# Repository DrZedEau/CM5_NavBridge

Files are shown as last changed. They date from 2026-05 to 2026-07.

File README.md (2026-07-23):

# CM5 NavBridge

A Raspberry Pi Compute Module 5 carrier board designed for BMW E-Series vehicles equipped with the OEM navigation system (E46, E39, E85, and similar platforms).

The CM5 NavBridge installs inline between the factory wiring harness and the BMW MK3/MK4 navigation module, allowing a Raspberry Pi CM5 to integrate with the original infotainment system while preserving the OEM look and functionalities.

Its primary purpose is to provide modern features such as Apple CarPlay and Android Auto through the Raspberry Pi while continuing to use the factory display, controls, and audio system.

<p align="center">
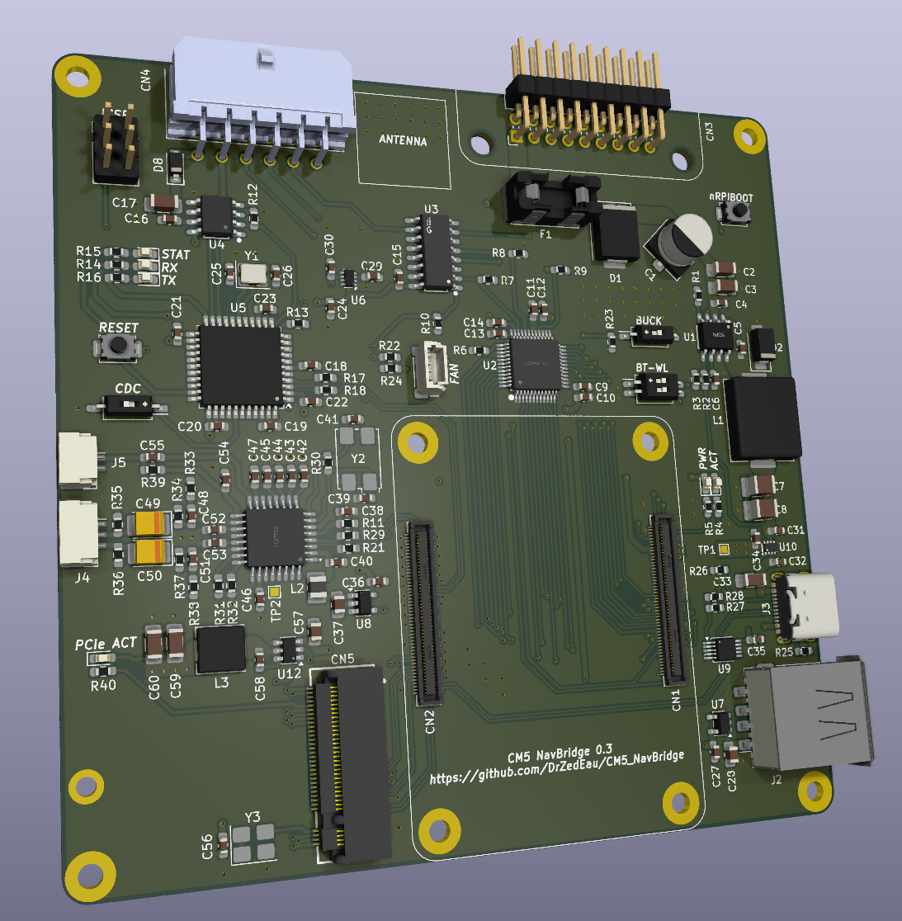
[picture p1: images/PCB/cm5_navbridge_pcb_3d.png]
  
</p>

---

## Overview

The board interfaces directly with the factory navigation module and provides:

- Video output from the Raspberry Pi to the OEM BMW display
- Stereo audio output for integration with the factory AUX input or CDC interface
- Microphone input supporting both OEM and aftermarket microphones
- Integration with the BMW I-Bus for power management and button control
- CDC emulation via the onboard microcontroller

The hardware is designed to work alongside the **LIVI** project, which provides the software environment for Apple CarPlay and Android Auto support.

Future software releases are planned to include a dedicated application, enabling the Raspberry Pi to function as a standalone infotainment platform with features such as:

- Music streaming
- Hands-free calling
- Navigation
- Media playback
- Additional connected vehicle features

---

## Features

### Hardware

- Automotive-grade 5V and 3.5A power supply using the **LMR14030-Q1**
- USB-C interface for Raspberry Pi flashing
- Automatic selection between USB-C and USB Type-A
- 24-bit video DAC (**ADV7125**) for OEM display output
- Integrated **PCM2912A** USB audio codec
  - Stereo line output
  - Mono microphone input
- M.2 PCIe M-Key (2230) expansion slot for additional modules such as GPS or DAB+

### Vehicle Integration

- Reads BMW I-Bus through an onboard **ATA663254** LIN transceiver
- **ATmega32U4** microcontroller for:
  - Raspberry Pi power management
  - OEM button translation
  - CD changer (CDC) emulation
- No modifications to the factory wiring or infotainment system are required

---

## Repository Structure

```text
hardware/      KiCad hardware design files
software/      Raspberry Pi software and MCU firmware
3D/            STL files for printed components
documentation/ Installation and project documentation
```

---

## Documentation

[0. Bill of materials](documentation/BOM.md)<br>

[1. Prepare the PCB](documentation/PCB.md)<br>

[2. Flash the NavBridge](documentation/FLASH.md)<br>

[3. Install the NavBridge](documentation/INSTALL.md)<br>

---

## Project Status

The hardware is currently functional and has been successfully tested on:

- BMW Z4 E86 with MK4 Navigation Module

Testing on additional E-Series platforms and navigation variants is ongoing.

---

## Roadmap

- Improve PCB layout for the next hardware revisions
- Expand compatibility testing across additional BMW platforms
- Develop a dedicated application

---

## Contributing

Contributions are welcome.

Bug reports, hardware improvements, firmware enhancements, and documentation updates are all appreciated. Please open an issue or submit a pull request if you would like to contribute.

---

## References

- LIVI project https://github.com/f-io/LIVI
- BMW Wiring Diagram System (WDS) https://bmwteka.com/wds/en/e85/e82460cf 
- BMW On-Board Monitor documentation https://bmwteka.com/wds/en/e85/1b7f9876
- Community resources https://www.e46fanatics.com/threads/bmw-on-board-monitor-without-navigation-unit.1303552

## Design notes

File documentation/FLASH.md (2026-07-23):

# Flash the RPI CM5

Locate the nRPIBOOT switch and press it down while connecting the USB-C cable to a PC:

<p align="center">
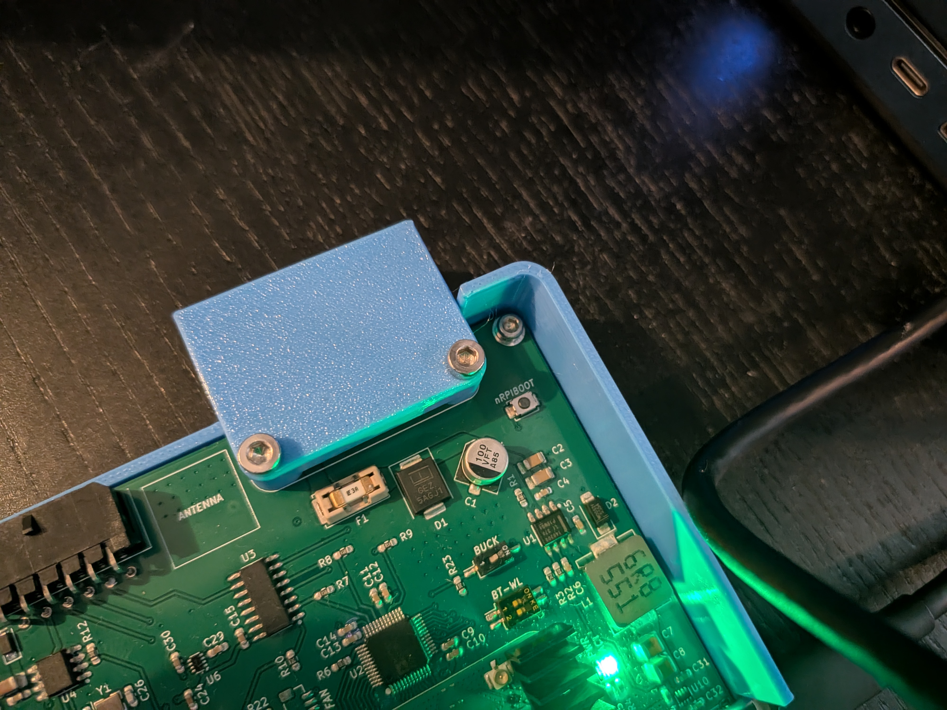
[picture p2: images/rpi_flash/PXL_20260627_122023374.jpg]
  
</p>

<p align="center">
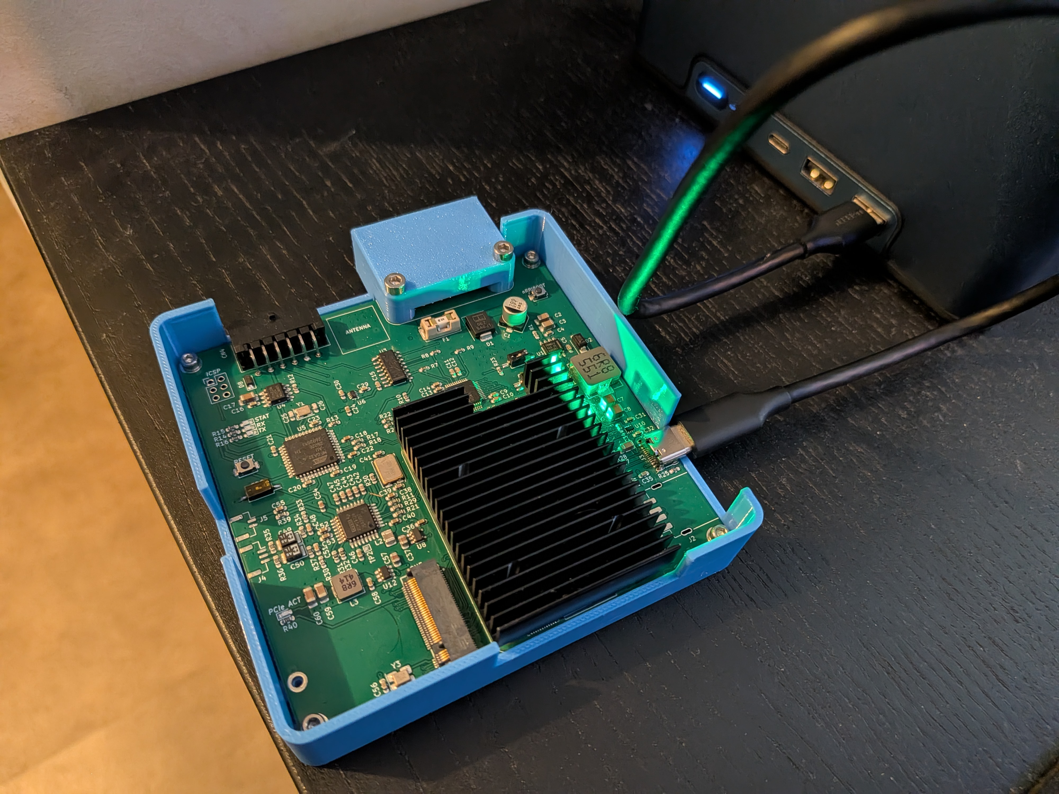
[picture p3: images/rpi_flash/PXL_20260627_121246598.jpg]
  
</p>

Once the CM5 has booted you can run the rpiboot tool on your PC so you can flash the CM5 with the Raspberry Pi imager tool.
Raspberry documentation on how to flash the Compute Module: https://www.raspberrypi.com/documentation/computers/compute-module.html#flash-compute-module-emmc

On the Raspberry Pi imager tool, select the CM5 board and your OS to install:

<p align="center">
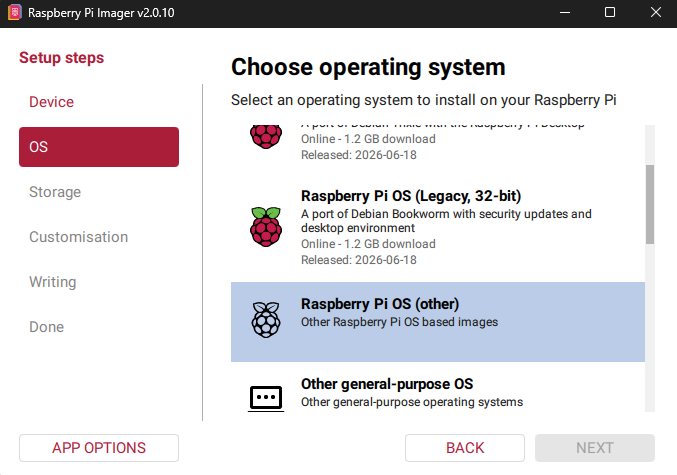
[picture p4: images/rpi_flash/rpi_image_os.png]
  
</p>

<p align="center">
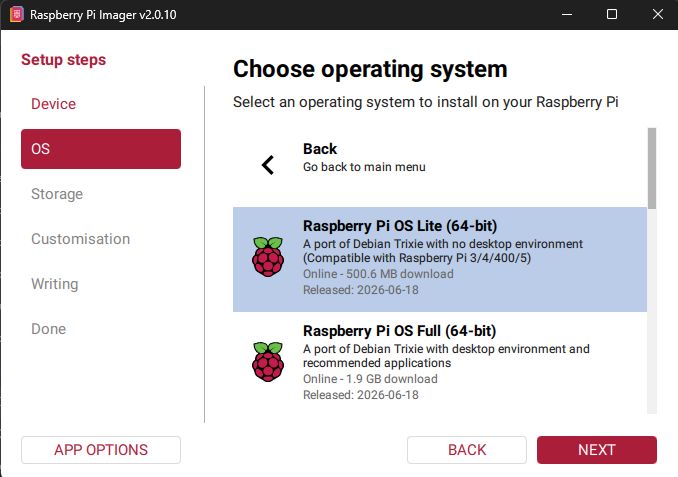
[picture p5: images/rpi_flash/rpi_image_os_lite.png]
  
</p>

Select your storage:

<p align="center">
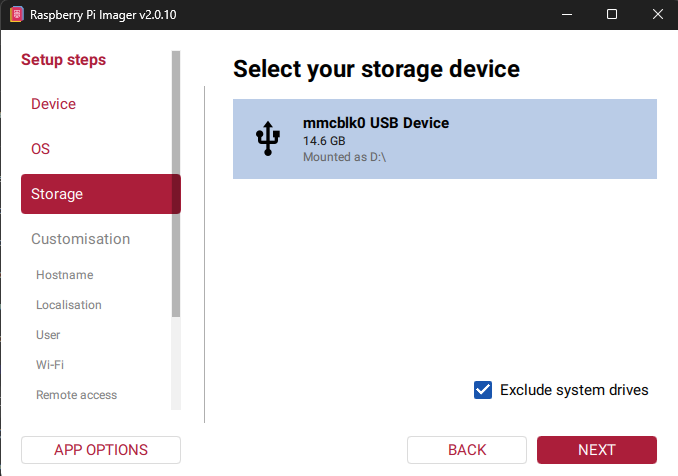
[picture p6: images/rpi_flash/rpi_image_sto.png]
  
</p>

Ensure SSH is enabled for post flash configuration:

<p align="center">
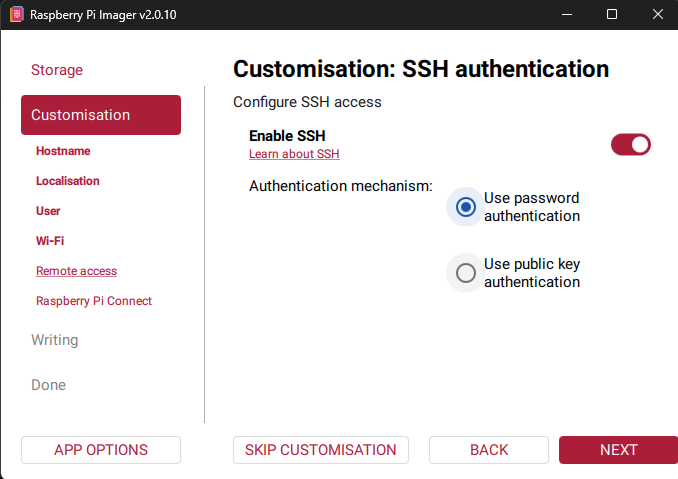
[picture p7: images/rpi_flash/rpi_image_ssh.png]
  
</p>

Once the flash has completed, unplug the board and connect it to a USB-C charger that can deliver at least 5V/3A.

<p align="center">
  
</p>

## Configure OS and install requirements

The RPI CM5 should boot (first boot takes some time) and be accessible via SSH. Once connected, run the following command to configure the OS:

```bash
curl -fsSL https://raw.githubusercontent.com/DrZedEau/CM5_NavBridge/dev/software/scripts/setup.sh | sudo bash
```

This script:
- removes packages and unused services to improve the boot time
- update OS and install required packages
- setup the csync script with the integrated RP1 chip
- setup the video output for the ADV7125 DAC chip with the 400*240p resolution (matched with OEM display)
- ensure volume is set to 100% on boot (below is to low for the car)
- installs a splash screen
- flashes the MCU when in bootloader mode (RESET switch on the board sets the MCU into bootloader mode and can be flashed from the OS)

Reboot the RPI with the following command:

```bash
sudo reboot
```

## Install LIVI 

To get Android Auto and Carplay on the RPI, I'm using this project https://github.com/f-io/LIVI <br>

Install the RPI-Lite OS version:

```bash
curl -fL -o install.sh https://raw.githubusercontent.com/f-io/LIVI/main/scripts/install/headless/install.sh
chmod +x install.sh
./install.sh
```

Then reboot 

```bash
sudo reboot
```

And reconnect to change the resolution for AA and Carplay (This resolution is twice what the OEM display is capable of but renders fine)

```bash
sed -i -E 's/"projectionWidth": *[0-9]+/"projectionWidth": 800/; s/"projectionHeight": *[0-9]+/"projectionHeight": 480/' ~/.config/LIVI/config.json
```

Finally you can shutdown the RPI:

```bash
sudo shutdown -h now
```

The board is now ready and can be installed inside the car

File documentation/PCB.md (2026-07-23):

# Assemble the board with the RPI CM5

Once you have assembled the PCB with its case it should look like this:

<p align="center">
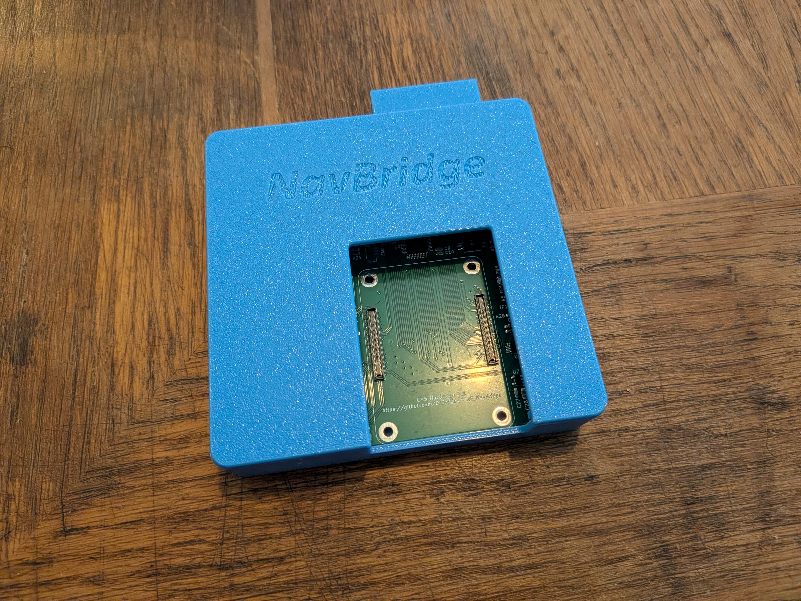
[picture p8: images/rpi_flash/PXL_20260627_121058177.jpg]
  
</p>

<p align="center">
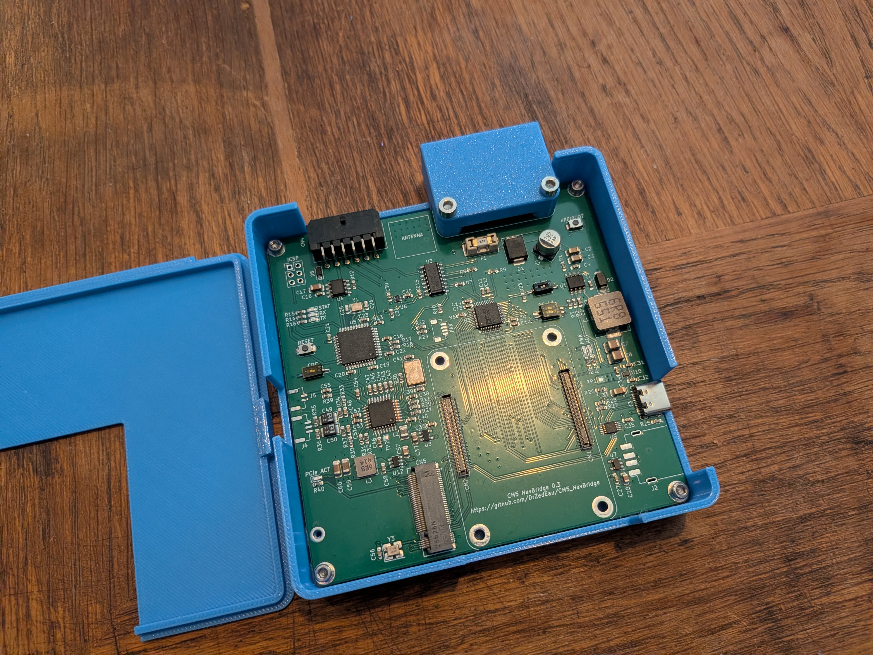
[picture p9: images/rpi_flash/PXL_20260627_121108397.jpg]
  
</p>

Install the RPI CM5 and ensure the CM5 is correclty connected to the PCB, you can also use M2.5 screws to secure it in place with the the heatsink:

<p align="center">
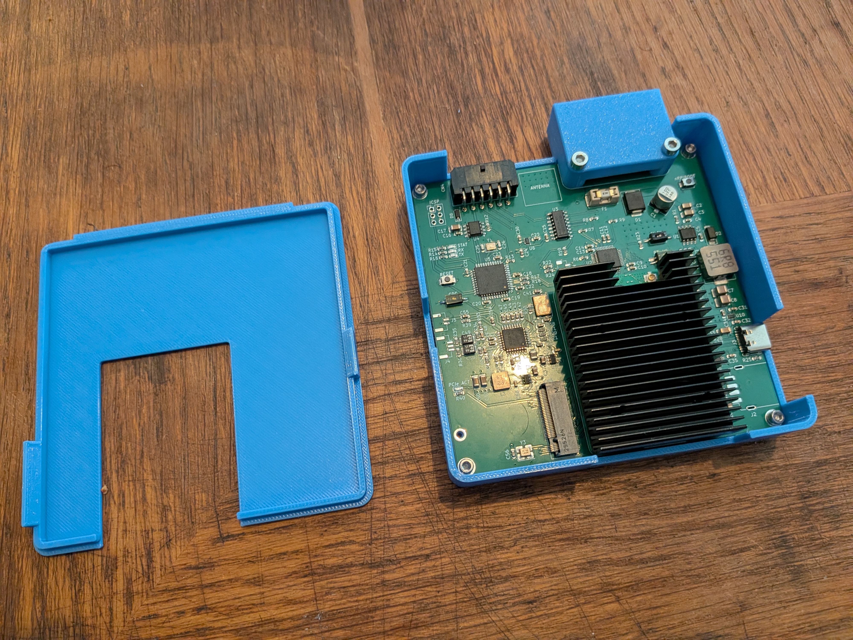
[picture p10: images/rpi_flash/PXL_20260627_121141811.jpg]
  
</p>

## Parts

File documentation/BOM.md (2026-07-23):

# BOM

| Part | Description |
| --- | --- |
| The assembled NavBridge PCB |  |
| 3D printed connector |  | 
| 3D printed case |  |
| DIY Cable for the NavBridge | Cable used from the NavBridge to the OEM Nav module | 
| DIY Cable for audio output | Cable wired to the AUX input or CDC for audio output |
| DIY Cable for audio input | Cable for electret microphone input (OEM or aftermaket) |
| A Raspberry Pi Compute Module 5 | The RPI CM5 lite version is not compatible with the PCB, a CM5 with eMMC is mandatory and preferably with at least 4GB of RAM | 
| CM5 Heatsink | Hightly recommended as the CM5 might throttle without heat dissipation |
| A USB dongle for AA/Carplay | Either a Carlinkit CPC200-CCPA or CPC200-CCPW (Newer version of LIVI do not require a dongle for Android phones) |

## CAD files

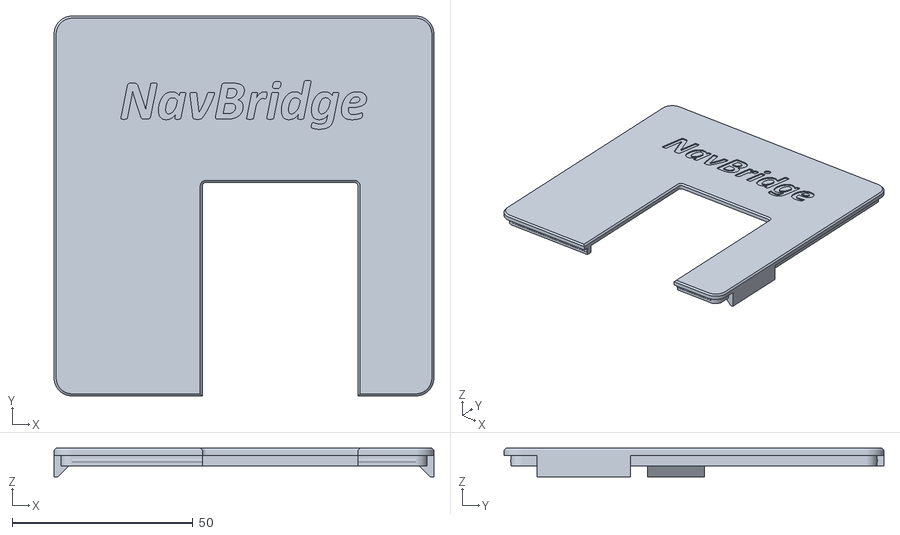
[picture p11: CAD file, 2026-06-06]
3D/CM5_NavBridge_V03_case_top.stl
105.0 x 105.0 x 8.00

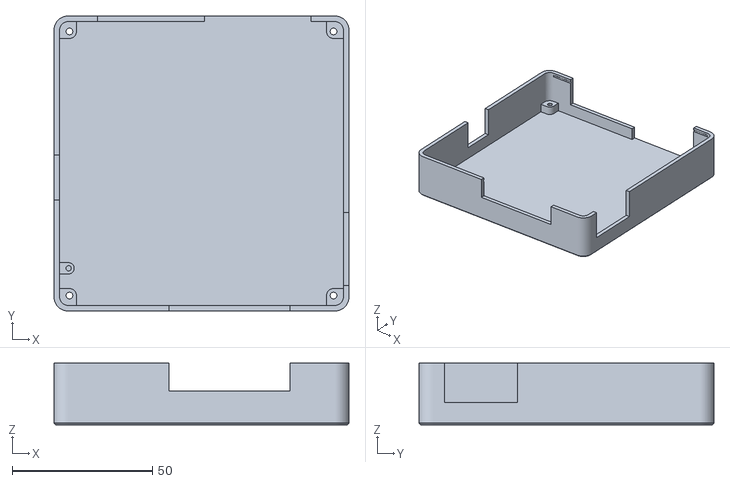
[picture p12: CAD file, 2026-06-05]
3D/CM5_NavBridge_V03_case_base.stl
105.0 x 105.0 x 22.0

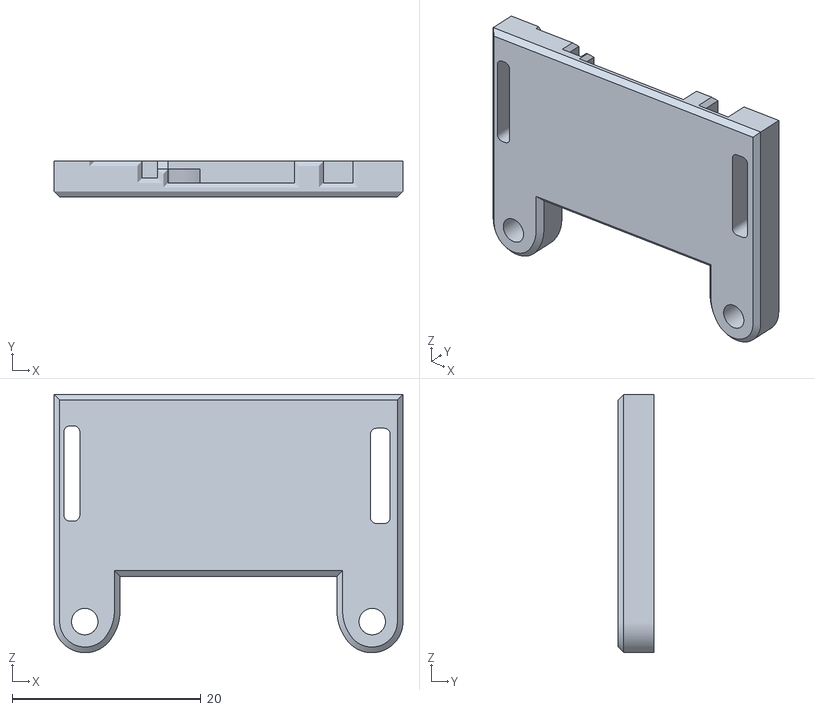
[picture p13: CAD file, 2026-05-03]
3D/BMW_NAV_Blue_Connector_part_2.stl
37.0 x 3.80 x 27.4

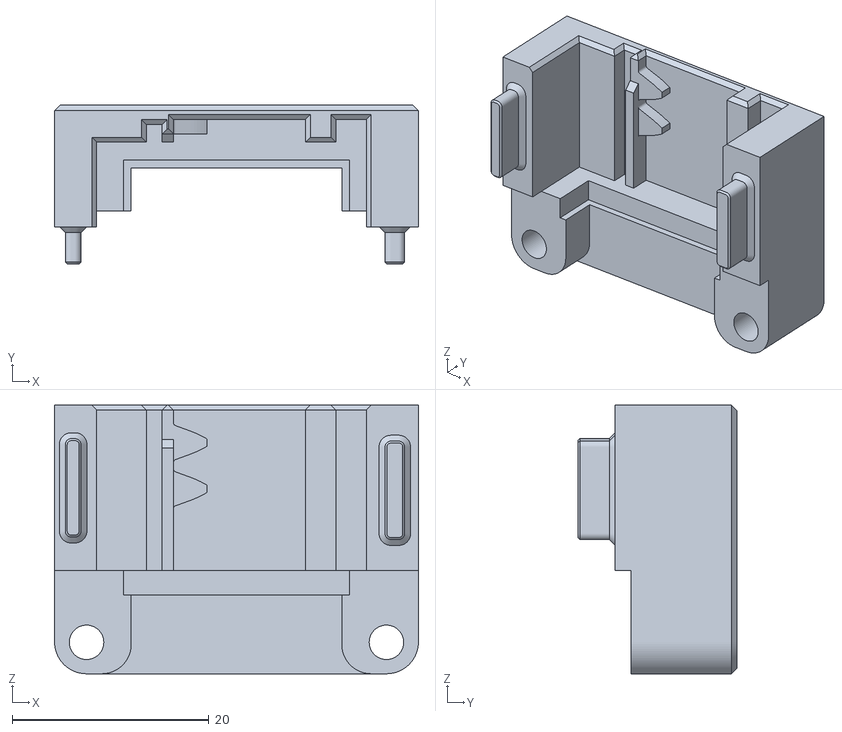
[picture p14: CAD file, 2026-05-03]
3D/BMW_NAV_Blue_Connector_part_1.stl
37.0 x 16.2 x 27.3

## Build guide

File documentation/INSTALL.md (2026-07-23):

# INSTALL THE NAVBRIDGE IN CAR

Below is the procedure to install the CM5 NavBridge on a E-Series BMW with Mk3 or Mk4 Nav module.<br>

## Wiring

The NavBrige uses two connectors:
- The connector marked CN3, is a standard 18 pins header with 2.54mm pitch. The X1313 (18 pins blue connector) from the Nav module should connect here. OEM X1313 connector is no longer available, to make the installation easier, I have designed a 3D model that can be printed and installed to imitate the OEM blue connector with the standard 18 pins header. The 3D printed parts uses two M3*16 to secure them together against the PCB.
- The connector marked CN4, is a standard 12 pins Molex MicroFit 3.0 connector. You have to create your own cable with the other end being the X1313 connector. You can use a white or black 18 pins connector (TE Connectivity 1379100-2) that is still available but you will have to cut off the extra plastic to fit with the blue connector on the Nav Module

### Make your own cable

Pin assignments at plug connector X1313

| Pin  number | Connection |
| --- | --- |
| 1 | Terminal 30 |
| 2 | Not used |
| 3 | IBUS |
| 4 | Not used |
| 5 | Analog Green  |
| 6 | Analog Blue |
| 7 | Analog Red |
| 8 | Not used |
| 9 | Nav Audio POS |
| 10 | Ground |
| 11 | Not used |
| 12 | Ground |
| 13 | Not used |
| 14 | Ground |
| 15 | Ground |
| 16 | Ground |
| 17 | Not used |
| 18 | Nav Audio NEG |

Pin assignments at plug connector Molex MicroFit 16 pins

| Pin  number | Connection |
| --- | --- |
| 1 | Ground |
| 2 | Ground |
| 3 | Ground |
| 4 | Ground |
| 5 | Ground |
| 6 | Nav Audio POS |
| 7 | Terminal 30 |
| 8 | IBUS |
| 9 | Analog Red |
| 10 | Analog Green  |
| 11 | Analog Blue |
| 12 | Nav Audio NEG |

Get the cables, connectors and contacts

<p align="center">
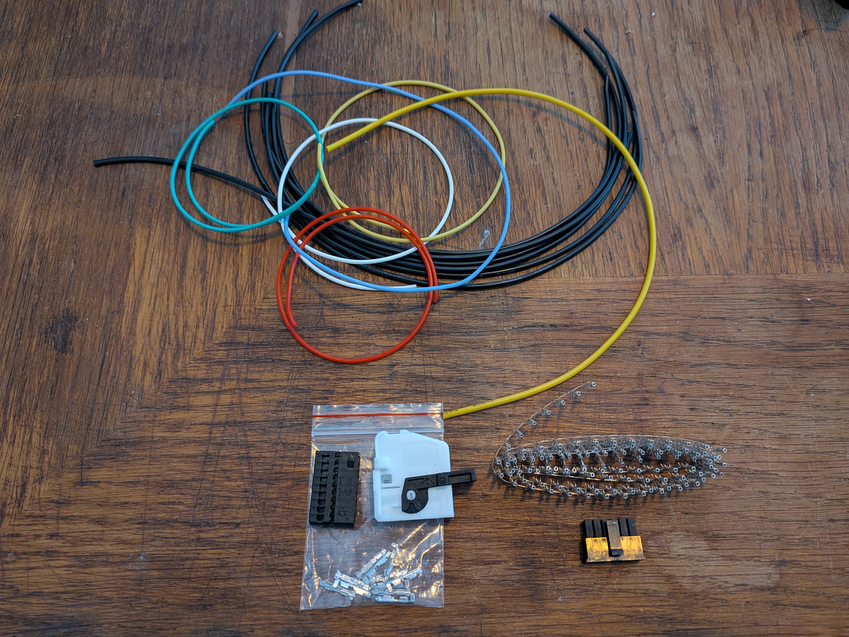
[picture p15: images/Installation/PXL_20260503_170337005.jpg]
  
</p>

Spend a lot of time stripping and crimping you cables

<p align="center">
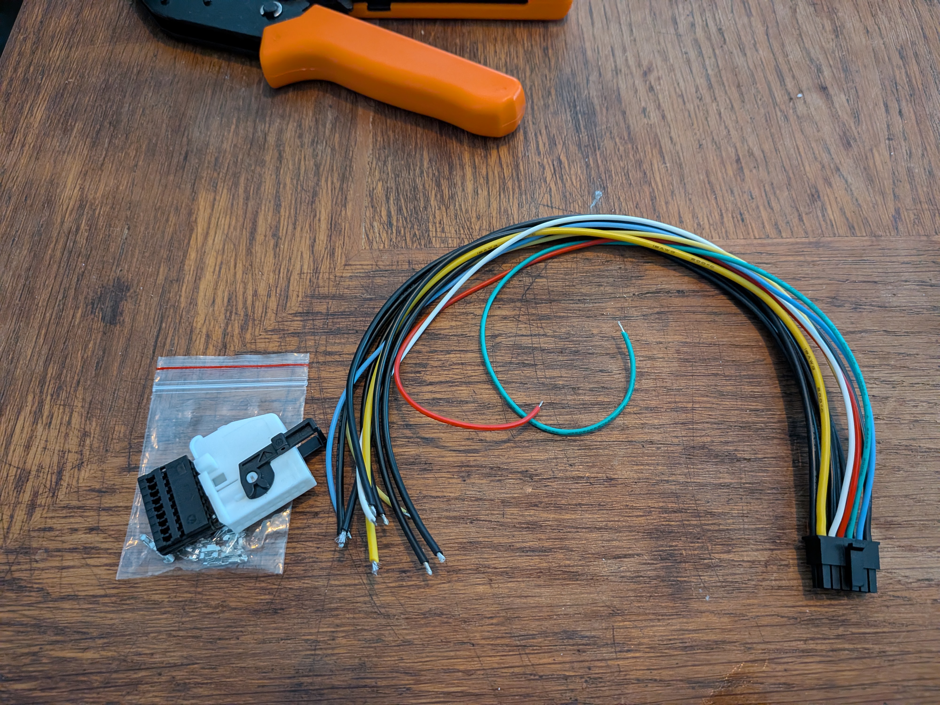
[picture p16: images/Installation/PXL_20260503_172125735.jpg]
  
</p>

<p align="center">
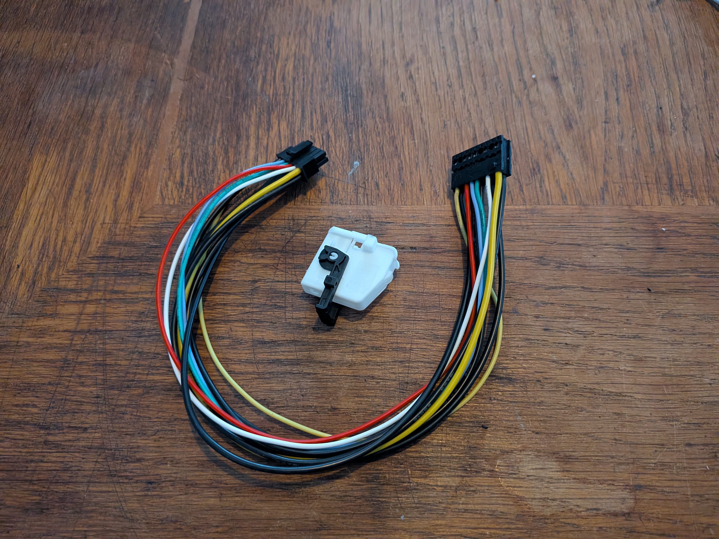
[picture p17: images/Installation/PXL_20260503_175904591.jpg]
  
</p>

Make it look nice

<p align="center">
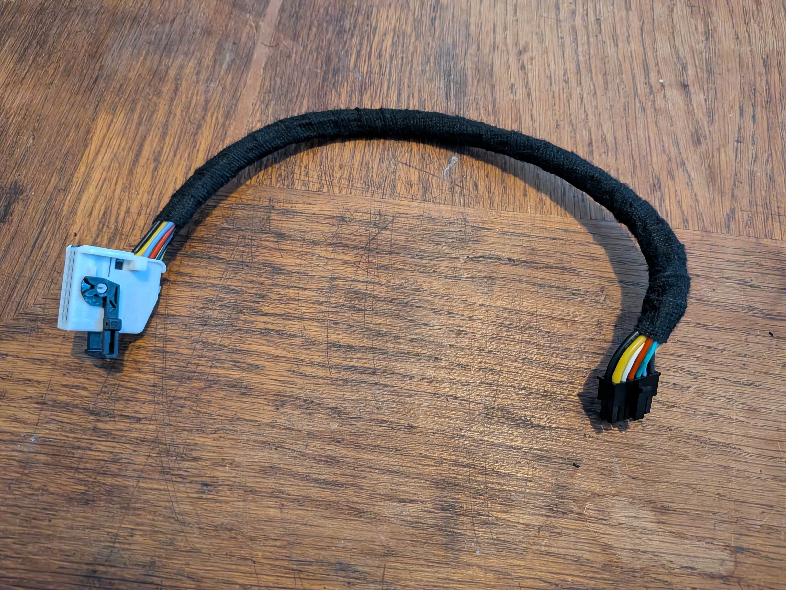
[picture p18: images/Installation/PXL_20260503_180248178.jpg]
  
</p>

## Install inside the car

Requirements: 
- Car battery disconnected

Remove the blue plug connector from the OEM Nav Module

<p align="center">
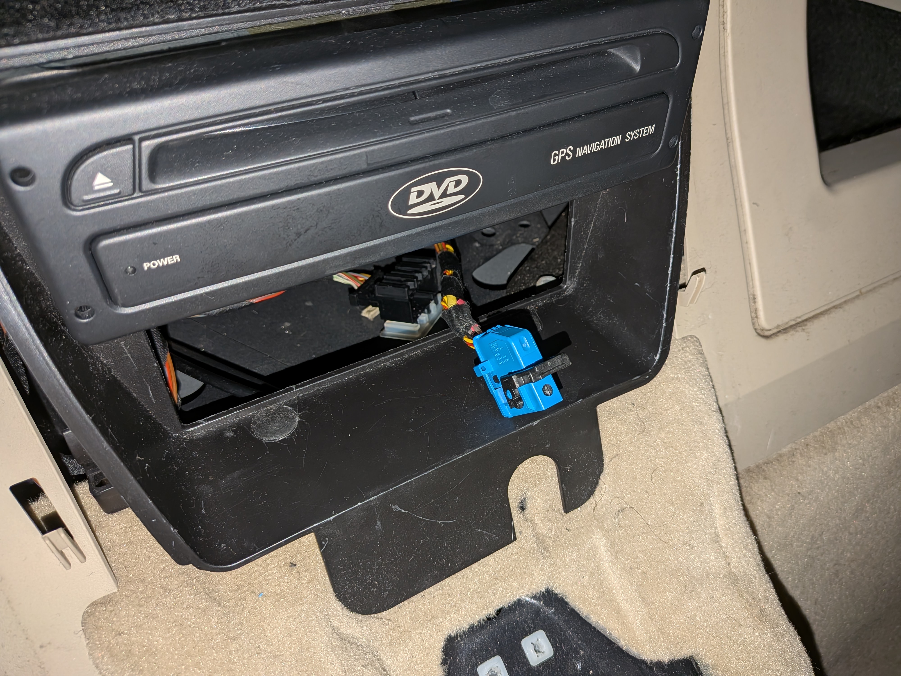
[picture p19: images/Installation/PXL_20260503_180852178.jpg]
  
</p>

Plug your DIY connector into the Nav Module

<p align="center">
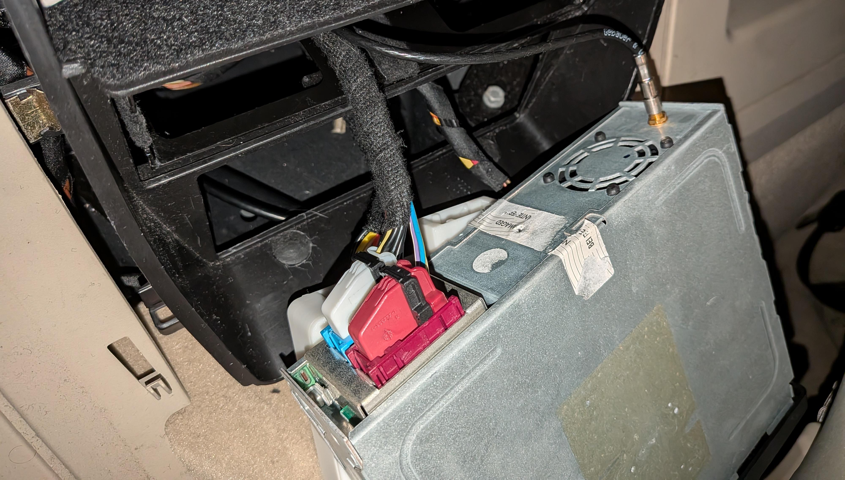
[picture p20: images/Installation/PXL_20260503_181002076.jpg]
  
</p>

Plug the blue connector from the car into the NavBridge

<p align="center">
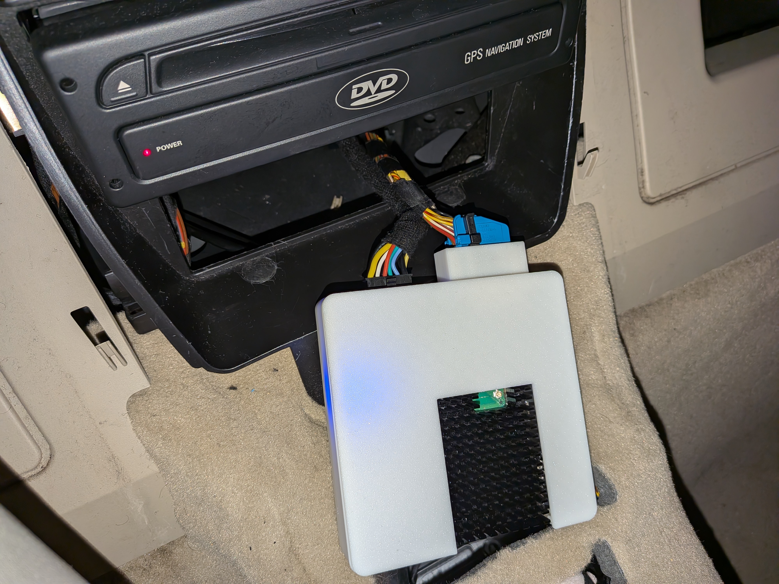
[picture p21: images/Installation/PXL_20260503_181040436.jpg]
  
</p>

Find a cosy spot for the NavBridge

<p align="center">
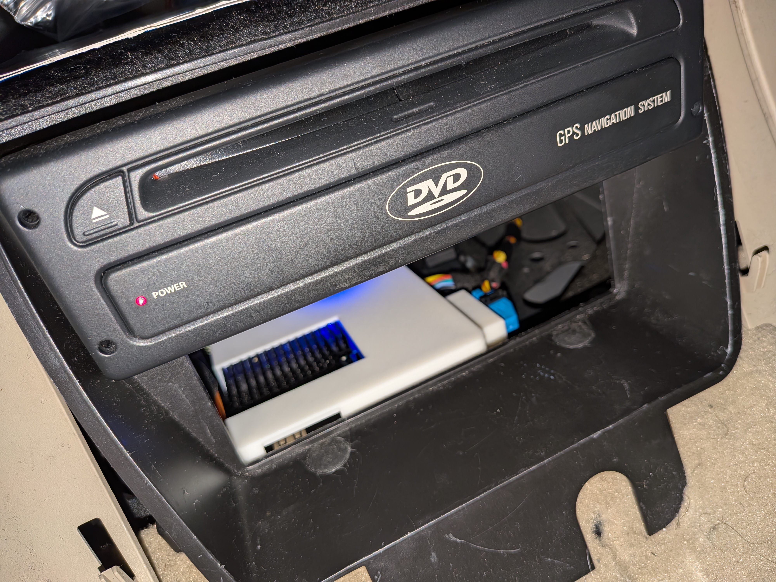
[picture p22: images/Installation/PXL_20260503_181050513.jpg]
  
</p>

With V0.2 no onbord sound car, so I'm using an external USB Audio output to the AUX of the car
<p align="center">
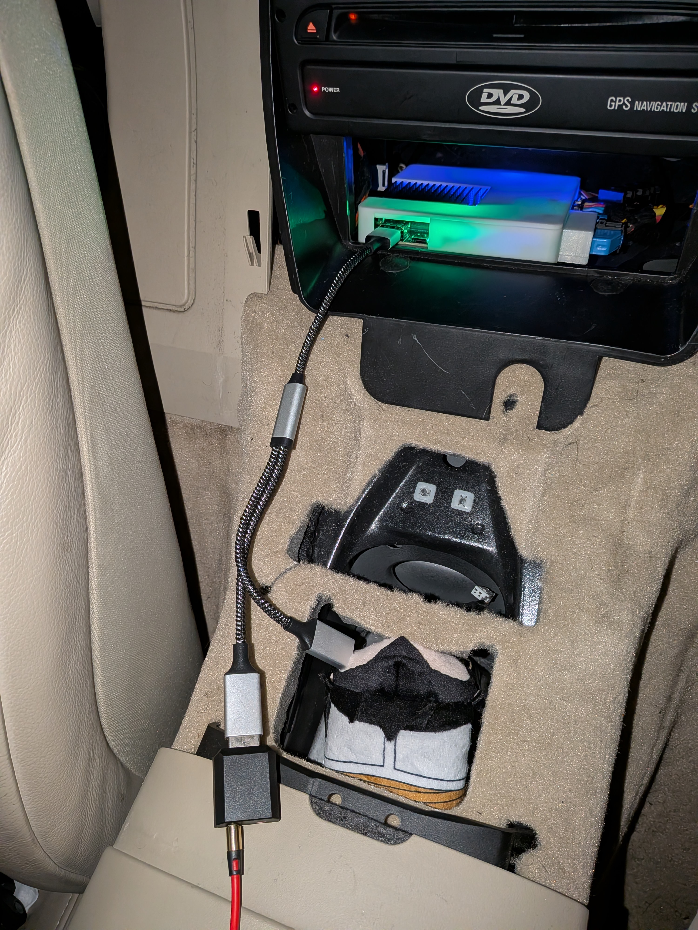
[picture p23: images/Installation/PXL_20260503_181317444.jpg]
  
</p>

Enjoy your favourite PSP Games on the OEM Display
<p align="center">
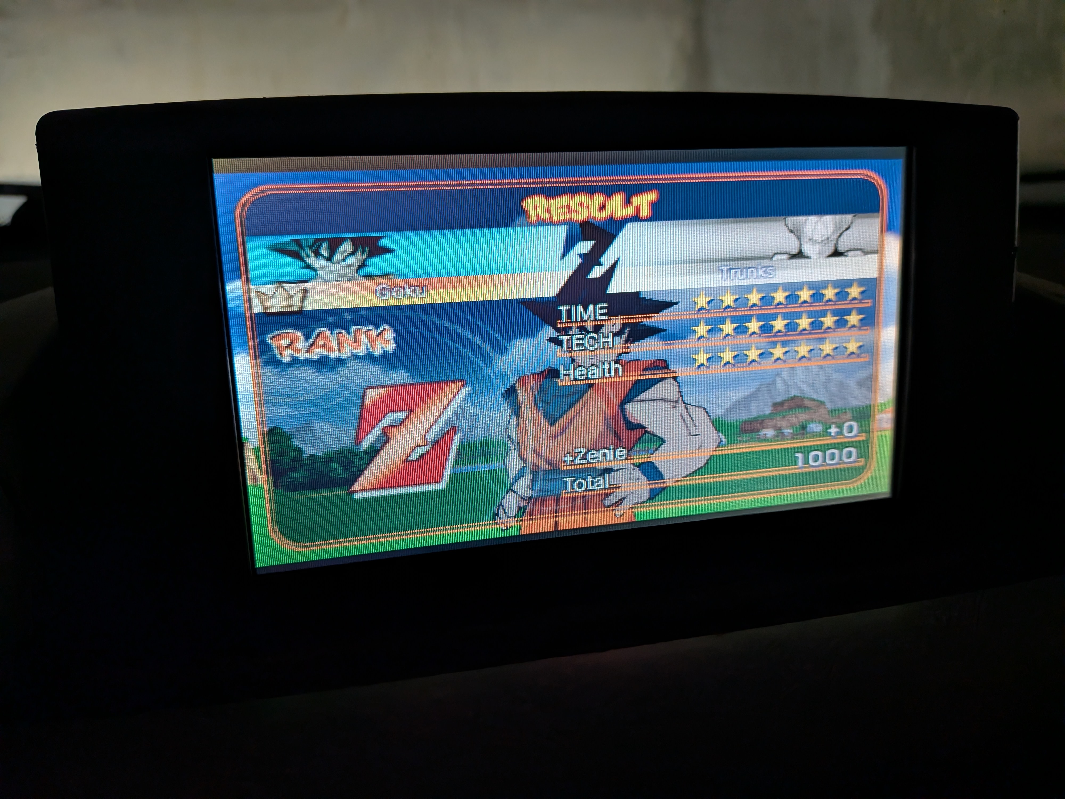
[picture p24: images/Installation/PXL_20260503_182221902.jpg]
  
</p>

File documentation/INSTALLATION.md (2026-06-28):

# INSTALL THE NAVBRIDGE IN CAR

Below is the procedure to install the CM5 NavBridge on a E-Series BMW with Mk3 or Mk4 Nav module.<br>

## Wiring

The NavBrige uses two connectors:
- The connector marked CN3, is a standard 18 pins header with 2.54mm pitch. The X1313 (18 pins blue connector) from the Nav module should connect here. OEM X1313 connector is no longer available, to make the installation easier, I have designed a 3D model that can be printed and installed to imitate the OEM blue connector with the standard 18 pins header. The 3D printed parts uses two M3*16 to secure them together against the PCB.
- The connector marked CN4, is a standard 12 pins Molex MicroFit 3.0 connector. You have to create your own cable with the other end being the X1313 connector. You can use a white or black 18 pins connector (TE Connectivity 1379100-2) that is still available but you will have to cut off the extra plastic to fit with the blue connector on the Nav Module

### Make your own cable

Pin assignments at plug connector X1313

| Pin  number | Connection |
| --- | --- |
| 1 | Terminal 30 |
| 2 | Not used |
| 3 | IBUS |
| 4 | Not used |
| 5 | Analog Green  |
| 6 | Analog Blue |
| 7 | Analog Red |
| 8 | Not used |
| 9 | Nav Audio POS |
| 10 | Ground |
| 11 | Not used |
| 12 | Ground |
| 13 | Not used |
| 14 | Ground |
| 15 | Ground |
| 16 | Ground |
| 17 | Not used |
| 18 | Nav Audio NEG |

Pin assignments at plug connector Molex MicroFit 16 pins

| Pin  number | Connection |
| --- | --- |
| 1 | Ground |
| 2 | Ground |
| 3 | Ground |
| 4 | Ground |
| 5 | Ground |
| 6 | Nav Audio POS |
| 7 | Terminal 30 |
| 8 | IBUS |
| 9 | Analog Red |
| 10 | Analog Green  |
| 11 | Analog Blue |
| 12 | Nav Audio NEG |

Get the cables, connectors and contacts

<p align="center">
  
</p>

Spend a lot of time stripping and crimping you cables

<p align="center">
  
</p>

<p align="center">
  
</p>

Make it look nice

<p align="center">
  
</p>

## Prepare the PCB

### 3D print the blue connector and install it

Requirements: 
- Two M3*16mm screws

<p align="center">
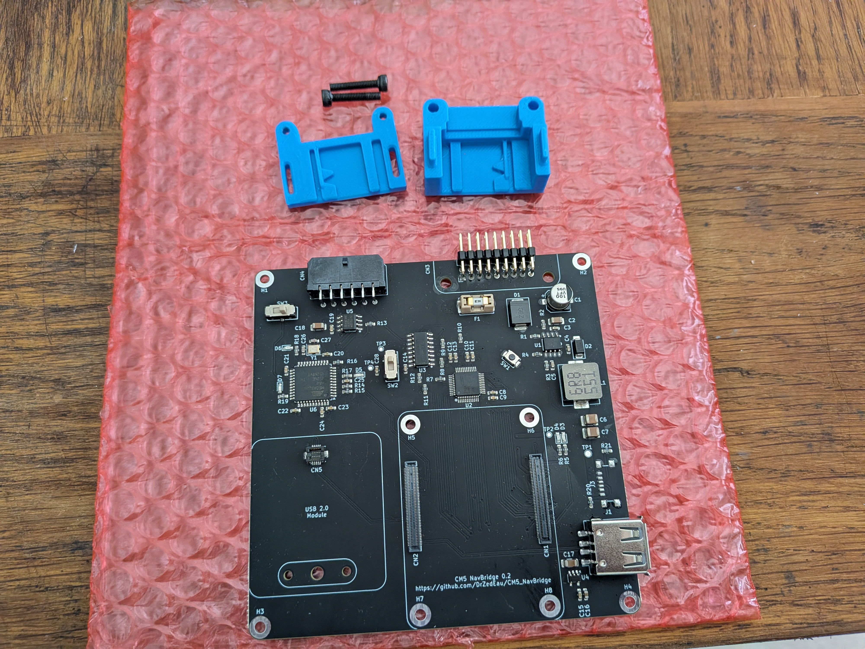
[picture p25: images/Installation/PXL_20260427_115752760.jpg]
  
</p>

<p align="center">
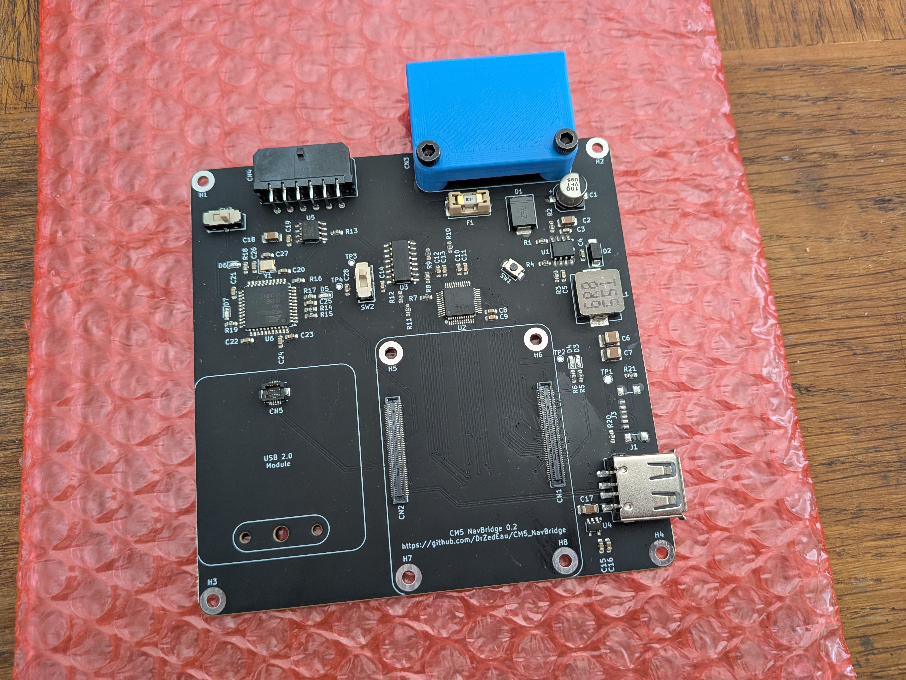
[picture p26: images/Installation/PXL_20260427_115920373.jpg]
  
</p>

<p align="center">
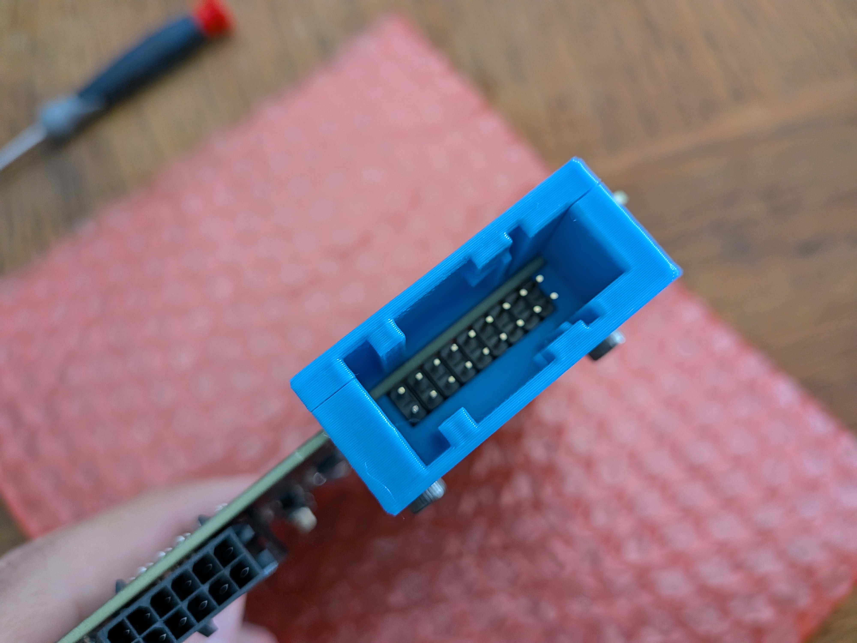
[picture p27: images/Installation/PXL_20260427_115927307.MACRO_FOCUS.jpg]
  
</p>

### 3D print the case and install the PCB

Requirements: 
- Four M2.5*8mm to secure the PCB to the case
- Four M2.5*8mm to install the CM5 heatsink 

<p align="center">
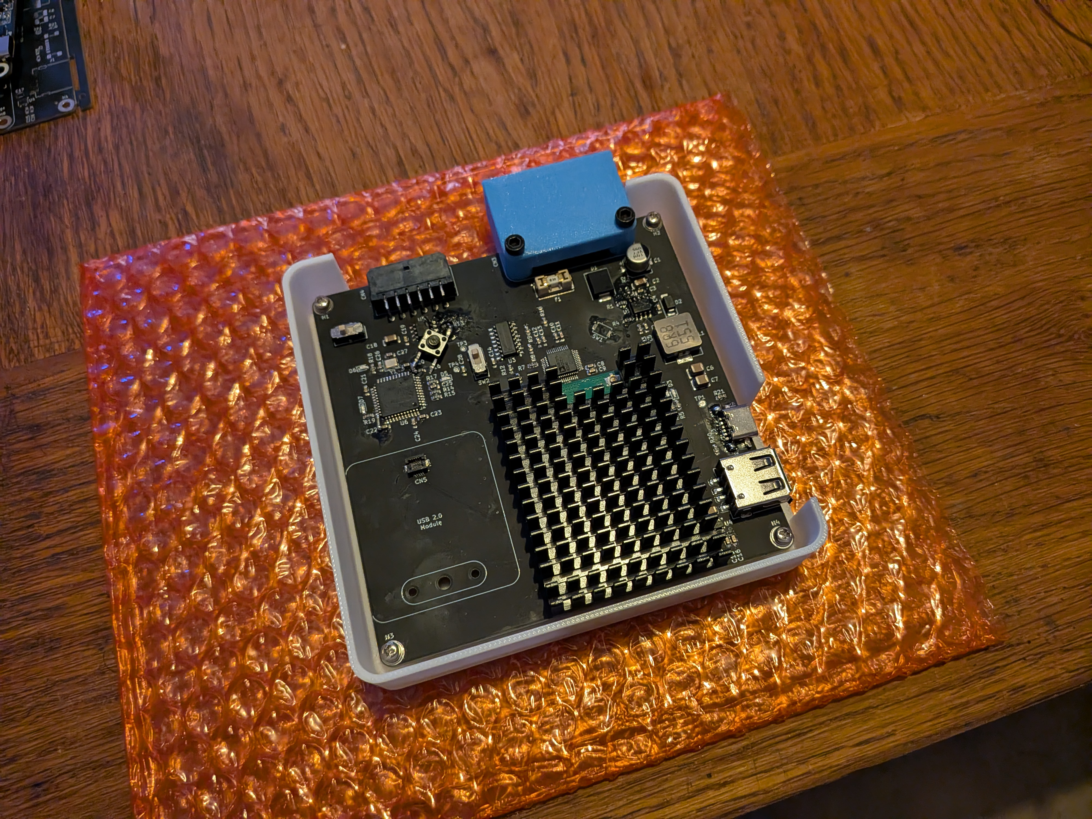
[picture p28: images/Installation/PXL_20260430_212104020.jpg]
  
</p>

<p align="center">
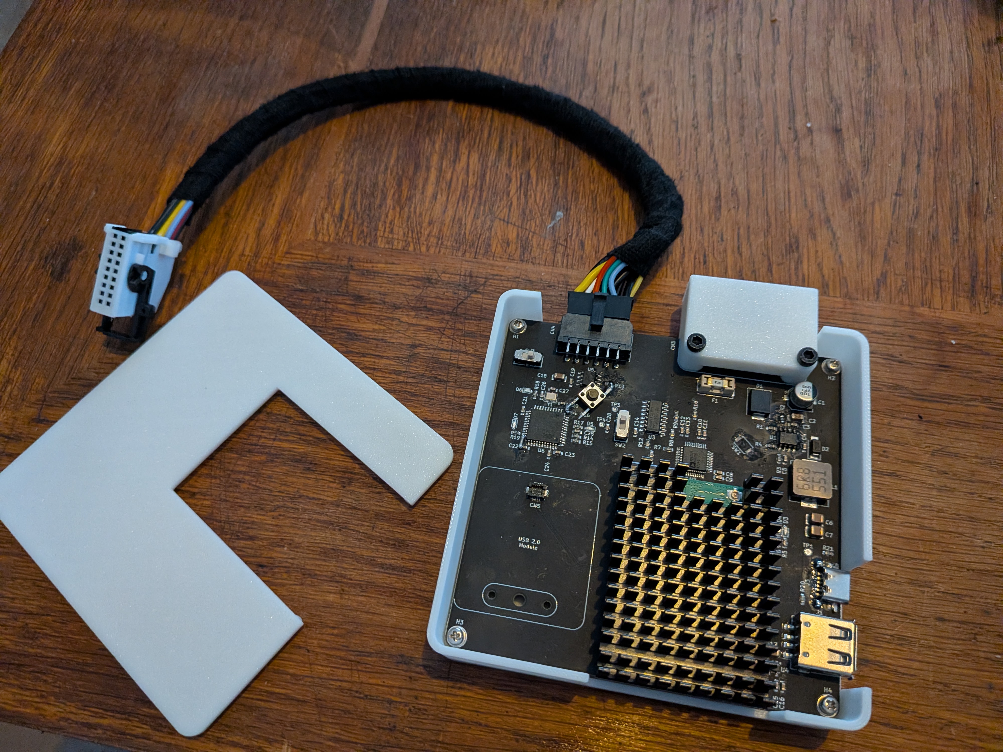
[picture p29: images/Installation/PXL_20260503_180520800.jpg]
  
</p>

<p align="center">
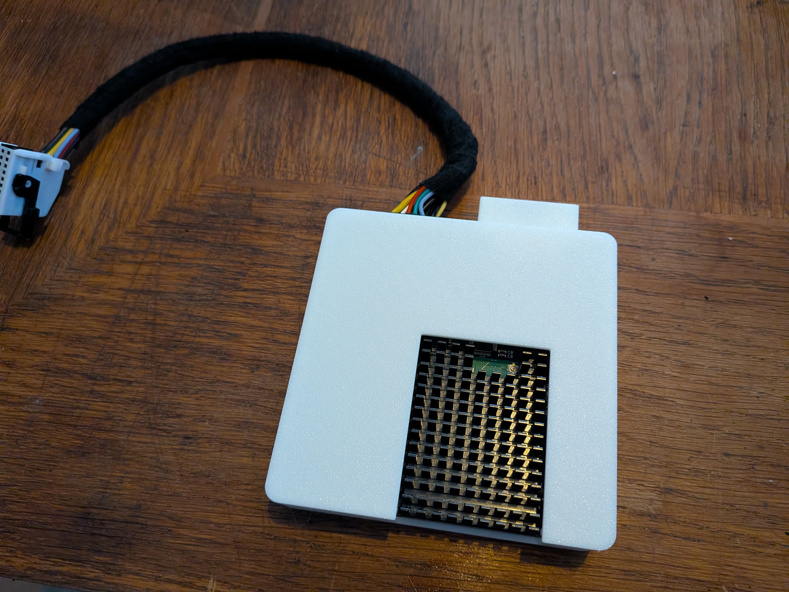
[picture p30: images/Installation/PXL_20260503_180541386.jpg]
  
</p>

<p align="center">
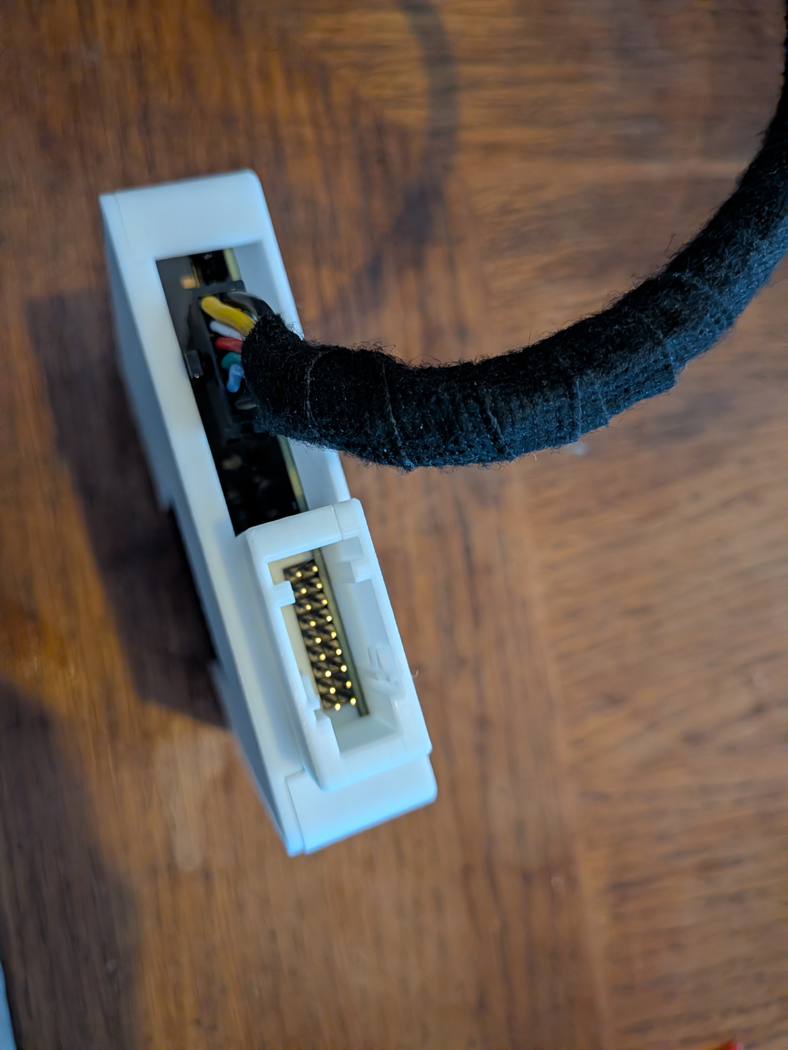
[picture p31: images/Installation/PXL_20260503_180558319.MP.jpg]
  
</p>

## Install inside the car

Requirements: 
- Car battery disconnected

Remove the blue plug connector from the OEM Nav Module

<p align="center">
  
</p>

Plug your DIY connector into the Nav Module

<p align="center">
  
</p>

Plug the blue connector from the car into the NavBridge

<p align="center">
  
</p>

Find a cosy spot for the NavBridge

<p align="center">
  
</p>

With V0.2 no onbord sound car, so I'm using an external USB Audio output to the AUX of the car
<p align="center">
  
</p>

Enjoy your favourite PSP Games on the OEM Display
<p align="center">
  
</p>

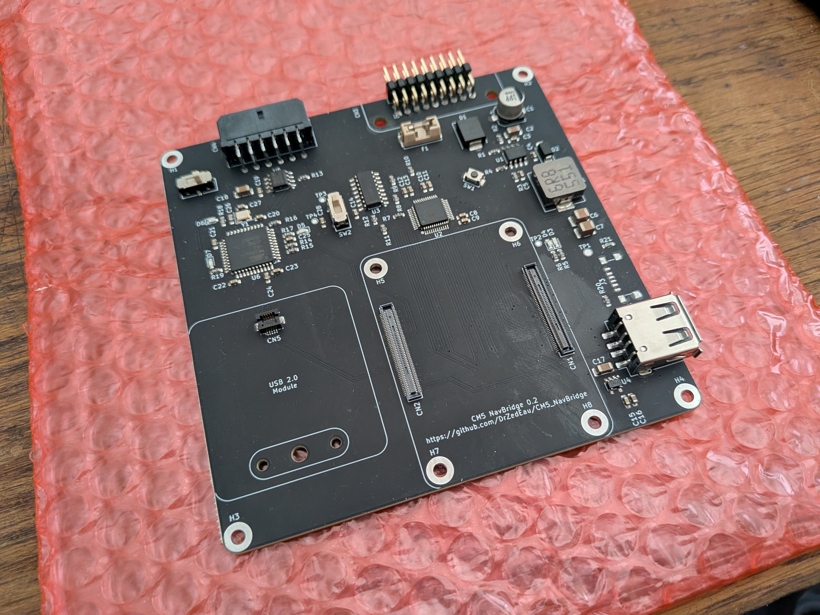
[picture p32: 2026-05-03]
images/Installation/PXL_20260427_113806471.jpg

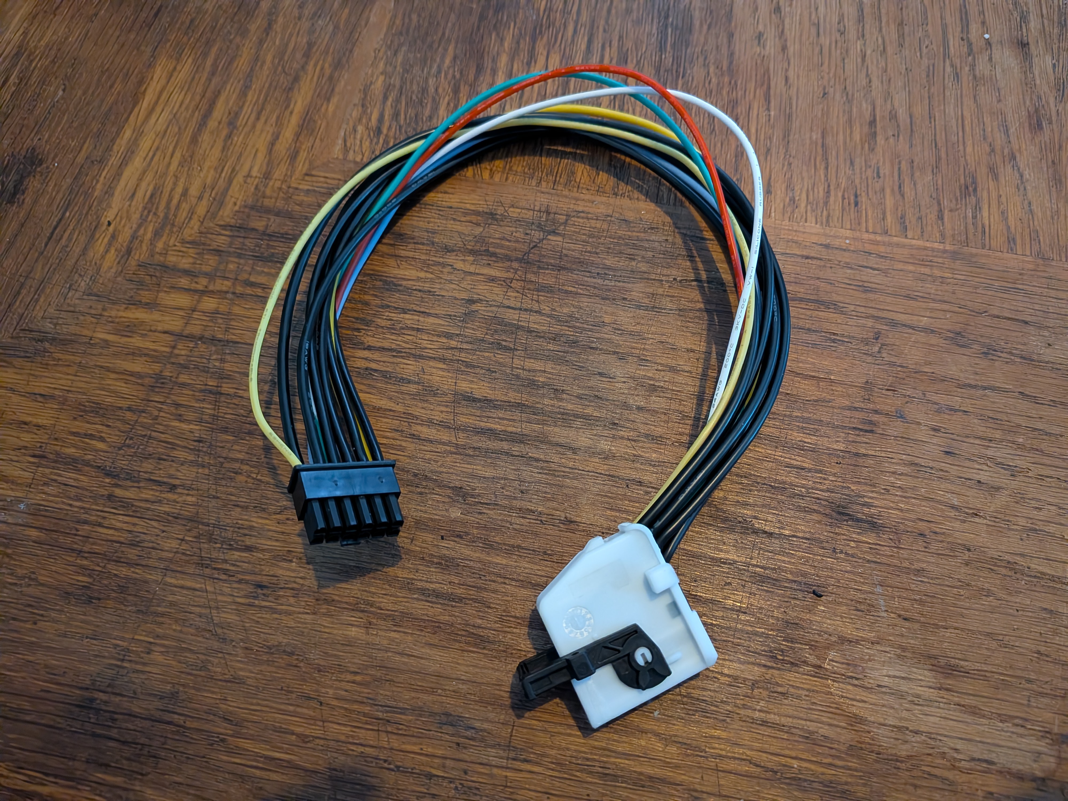
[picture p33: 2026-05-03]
images/Installation/PXL_20260503_175937081.jpg

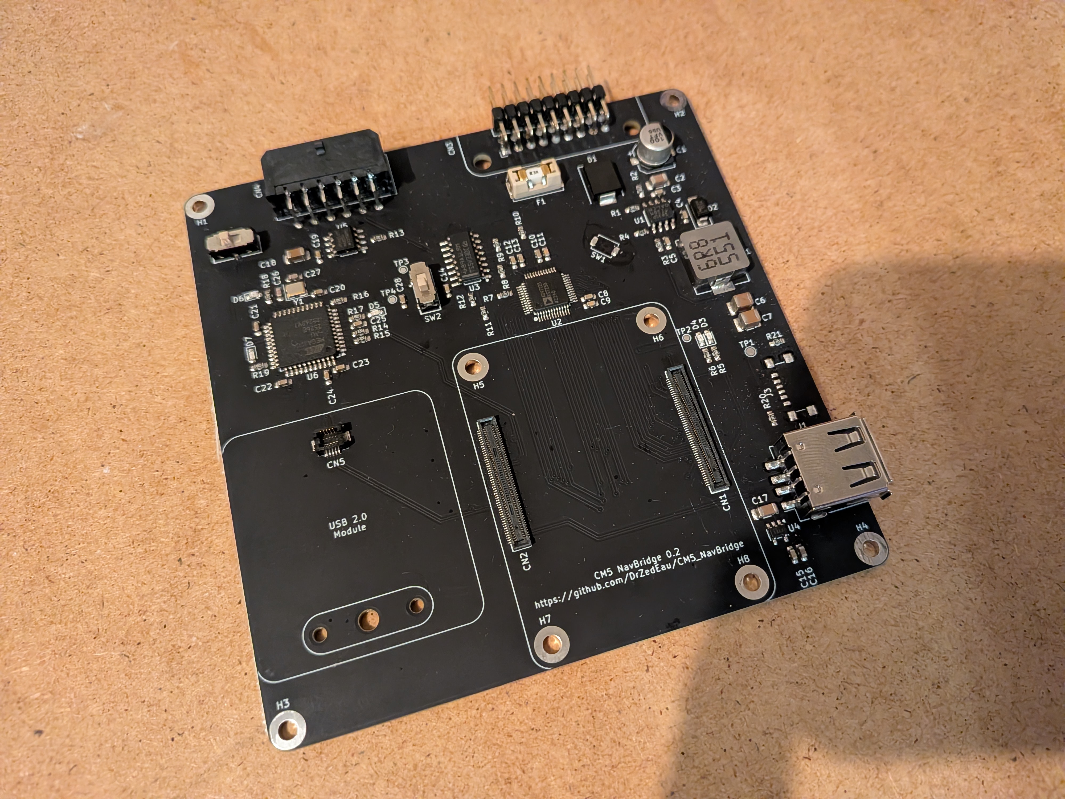
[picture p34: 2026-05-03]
images/Installation/PXL_20260428_204908077.jpg

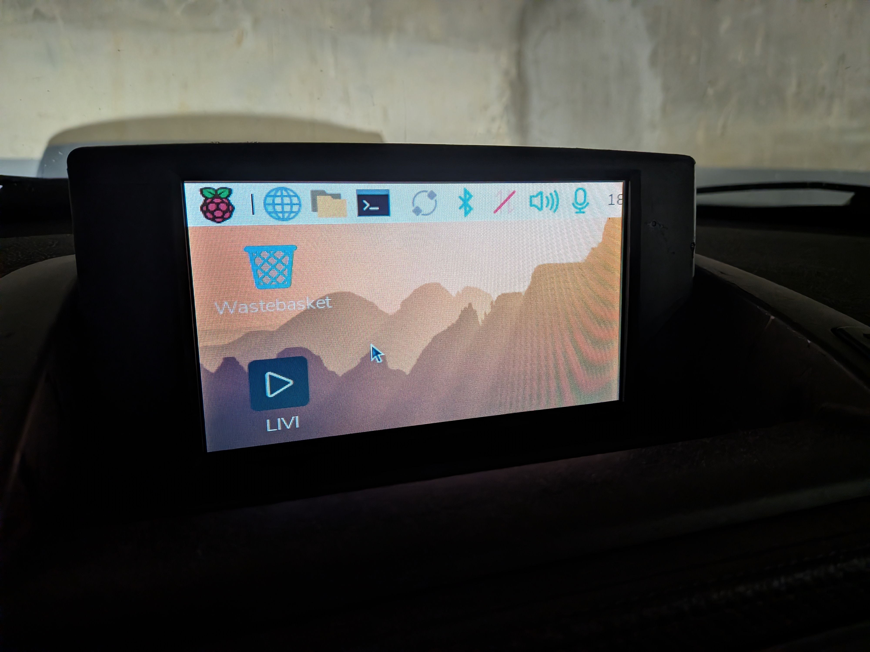
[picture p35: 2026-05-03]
images/Installation/PXL_20260503_181438624.jpg

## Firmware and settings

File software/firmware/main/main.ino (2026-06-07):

#include <Arduino.h>
#include <IbusTrx.h>
#include <Keyboard.h>
#include <avr/power.h>
#include "IbusMessages.h"

IbusTrx ibusTrx;

// STAT LED
const uint8_t MCU_STAT_LED = 13;

// RPI PWR_Button pin
const uint8_t RPI_PWR_BUTTON = 7;

// BUCK control
const uint8_t BUCK_EN = A3;

// Analog RGB Switcher control
const uint8_t SWITCHER_IN = A4;

// Analog RGB Switcher control
const uint8_t ADV_DAC_EN = A5;

// LIN control
const uint8_t LIN_EN = 11;

// Timeout when no IBUS activity
static unsigned long lastIbusActivityMs = 0;
static bool slept = false;

// Timeout set to 30 seconds of inactivity
const unsigned long IBUS_INACTIVITY_TIMEOUT_MS = 30000;

// SELECT button toggles between Arrow UP and Arrow DOWN
static bool selectSendsUp = true;

// Only send USB keystrokes when RPI Analog RGB output is enabled
static inline bool rpiAnalogRgbEnabled() {
  return digitalRead(SWITCHER_IN) == LOW;
}

static void sendKey(uint8_t key, uint8_t times = 1) {
  if (!rpiAnalogRgbEnabled()) return;
  for (uint8_t i = 0; i < times; i++) {
    Keyboard.write(key);
  }
}

static void rpiPwrButtonPress(unsigned long ms = 200) {
  pinMode(RPI_PWR_BUTTON, OUTPUT);
  digitalWrite(RPI_PWR_BUTTON, LOW);   // pull CM5 PWR_Button low
  delay(ms);
  pinMode(RPI_PWR_BUTTON, INPUT);      // release button press
}

static void powerBuck(uint8_t pinState) {
  pinMode(BUCK_EN, OUTPUT);
  digitalWrite(BUCK_EN, pinState);
}

static void analogRgbInput(uint8_t pinState) {
  pinMode(SWITCHER_IN, OUTPUT);
  digitalWrite(SWITCHER_IN, pinState);
}

static void advDacControl(uint8_t pinState) {
  pinMode(ADV_DAC_EN, OUTPUT);
  digitalWrite(ADV_DAC_EN, pinState);
}

static void controlLin(uint8_t pinState) {
  pinMode(LIN_EN, OUTPUT);
  digitalWrite(LIN_EN, pinState);
}

static void SleepMode() {
  // Stop UART so TXD is LOW
  Serial1.end();

  // Force TXD low
  pinMode(1, OUTPUT);
  digitalWrite(1, LOW);

  delay(50); // Ensure TXD is stable low

  // Sleep mode on LIN transceiver
  controlLin(LOW);

  delay(50);
}

void setup() {
  clock_prescale_set(clock_div_1);

  // Disable JTAG on PF4-PF7.
  // Must write JTD twice within 4 cycles.
  MCUCR |= (1 << JTD);
  MCUCR |= (1 << JTD);

  // Make sure the PWR Button pin is input (LOW will prevent the RPI form booting)
  pinMode(RPI_PWR_BUTTON, INPUT);

  // Power the onboard STAT LED
  pinMode(MCU_STAT_LED, OUTPUT);
  digitalWrite(MCU_STAT_LED, HIGH);

  // Ensure BUCK is disabled on MCU boot 
  powerBuck(LOW);

  // Analog RGB input from NAV module on startup
  analogRgbInput(HIGH);

  // Make sure LIN transceiver is in normal mode
  controlLin(HIGH);

  advDacControl(LOW);

  // IBUS is 9600 8E1 on BMW
  Serial1.begin(9600, SERIAL_8E1);
  ibusTrx.begin(Serial1);
  lastIbusActivityMs = millis();
  slept = false;

  // USB HID init    
  Keyboard.begin();
  delay(500);

}

void loop() {

  // Read complete IBUS messages via IbusTrx
  if (ibusTrx.available()) {
    IbusMessage msg = ibusTrx.readMessage();
    lastIbusActivityMs = millis();

    // // IGN handling
    if (ibusIsIgnPos2(msg)) {
      powerBuck(HIGH);  // Enable the BUCK to power the RPI when IGN POS2 is detected on IBUS
      advDacControl(HIGH); // Enable Video DAC when RPI boots
    }
    if (ibusIsIgnOff(msg)) {
      advDacControl(LOW); // Disable Video DAC when RPI is about to shutdown
      rpiPwrButtonPress(); // Send graceful power off to the RPI when IGN OFF is detected on IBUS
      delay(3000); // Wait for RPI to completely shut down
      powerBuck(LOW); 
    }

    if (ibusIsTelephonePressed(msg)) {
      analogRgbInput(digitalRead(SWITCHER_IN) == HIGH ? LOW : HIGH);
    }

    // Force back to NAV RGB input (disable RPI analog RGB) when the buttons below are pressed
    if (ibusIsAmPressed(msg) || ibusIsFmPressed(msg) ||
              ibusIsTonePressed(msg) || ibusIsMenuPressed(msg) ||
              ibusIsModePressed(msg) || ibusIsInfoPressed(msg) ||
              ibusIsRadioBmPressed(msg)) {
      analogRgbInput(HIGH);
    }

    // Keyboard strokes for each radio buttons presses
    if (ibusIsPreset1Pressed(msg)) {
      sendKey('h');
    } else if (ibusIsPreset2Pressed(msg)) {
      sendKey(KEY_BACKSPACE);
    } else if (ibusIsPreset3Pressed(msg)) {
      sendKey('p');
    } else if (ibusIsPreset4Pressed(msg)) {
      sendKey('s');
    } else if (ibusIsPreset5Pressed(msg)) {
      sendKey(KEY_UP_ARROW);
    } else if (ibusIsPreset6Pressed(msg)) {
      sendKey(KEY_DOWN_ARROW);

    } else if (ibusIsMflSendEndPressed(msg)) {
      sendKey('v');
    } else if (ibusIsMflModeTogglePressed(msg)) {
      sendKey('a');
    }

    if (ibusIsSearchUpPressed(msg)) {
      sendKey('n');
    } else if (ibusIsSearchDownPressed(msg)) {
      sendKey('b');
    } else if (ibusIsSearchLeftPressed(msg)) {
      sendKey('b');
    } else if (ibusIsSearchRightPressed(msg)) {
      sendKey('n');
    } else if (ibusIsSelectPressed(msg)) {
      sendKey(selectSendsUp ? KEY_UP_ARROW : KEY_DOWN_ARROW);
      selectSendsUp = !selectSendsUp;
    } else if (ibusIsBmKnobPressed(msg)) {
      sendKey(KEY_RETURN);
    } else if (ibusIsBmKnobRight(msg, 1)) {
      sendKey(KEY_RIGHT_ARROW, 1);
    } else if (ibusIsBmKnobRight(msg, 2)) {
      sendKey(KEY_RIGHT_ARROW, 2);
    } else if (ibusIsBmKnobRight(msg, 3)) {
      sendKey(KEY_RIGHT_ARROW, 3);
    } else if (ibusIsBmKnobRight(msg, 4)) {
      sendKey(KEY_RIGHT_ARROW, 4);
    } else if (ibusIsBmKnobLeft(msg, 1)) {
      sendKey(KEY_LEFT_ARROW, 1);
    } else if (ibusIsBmKnobLeft(msg, 2)) {
      sendKey(KEY_LEFT_ARROW, 2);
    } else if (ibusIsBmKnobLeft(msg, 3)) {
      sendKey(KEY_LEFT_ARROW, 3);
    } else if (ibusIsBmKnobLeft(msg, 4)) {
      sendKey(KEY_LEFT_ARROW, 4);
    }
  }
  // Sleep mode for the LIN transceiver when no IBUS activity detected for 10 seconds (Car is off and closed)
  if (!slept && (millis() - lastIbusActivityMs > IBUS_INACTIVITY_TIMEOUT_MS)) {
    SleepMode();
    slept = true;   // prevent calling SleepMode() repeatedly
  }

}

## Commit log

2026-04-24 updated Readme and added 3D models for OEM connector
    [BMW_NAV_Blue_Connector_part_1.stl, BMW_NAV_Blue_Connector_part_2.stl]
2026-05-03 few updates
    [BMW_NAV_Blue_Connector_part_1.stl, BMW_NAV_Blue_Connector_part_2.stl, CM5_NavBridge_V02_case_base.stl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]
2026-05-09 updated the documentation
    * updated the documentation
    * fixed images paths
    [main.ino]
2026-06-03 disable JTAG on MCU to use PF4 pin as GPIO
2026-06-05 new version of the case for PCB v0.3
    [CM5_NavBridge_V02_case_base.stl, CM5_NavBridge_V02_case_top.stl, CM5_NavBridge_V03_case_base.stl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]
2026-06-05 Kicad project for CM5_NavBridge PCB v0.3
2026-06-06 Added NavBridge text to cover
    [CM5_NavBridge_V03_case_top.stl]
2026-06-07 simulate pwr button press to power off the rpi gracefully
2026-06-20 updated the script to adjust audio volume on rpi startup with timer 5s after boot
2026-06-27 Added documentation to prepare and install the CM5/PCB
2026-06-27 Table for BOM
